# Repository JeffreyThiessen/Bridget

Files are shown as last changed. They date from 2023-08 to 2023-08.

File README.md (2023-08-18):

# Bridget Custom
This repo has my custom stl files for Flatbox rev4 PCB's, modified from SGF Devices repo.

finished

files https://github.com/JeffreyThiessen/Bridget/tree/main/v2_custom

read [v2_custom/v2_custom.md](https://github.com/JeffreyThiessen/Bridget/blob/main/v2_custom/v2_custom.md) for details

# Bridget
3D Printable Files for SGF Bridget controller. The case is a modified version of the Flatbox rev4 by jfedor (https://github.com/jfedor2/flatbox). The buttons are a modified version of the Egg On Rice buttons by b1nc (https://github.com/b1nc/Egg-On-Rice-Controller). It is designed to fit a Flatbox rev4 PCB without modification.  
  
v1 of this case is no longer used. v2 was developed to increase rigidity, ease assembly, and allow for future additions. When assembling v2, tolerances are tight and may require a SMALL amount of pressure to seat the sides into other pieces. If the pieces do not snap together with small amounts of force, your printer/filament may need tuning to print the dimensions more accurately, or you may need to do some sanding. You can also always go back to printing v1.  
  
Each case requires the following for full assembly:  
1x top case  
1x bottom case  
2x sides - IMPORTANT NOTE - the portion of the side panel that seats into the top case is deeper than the portion that seats into the bottom case. If your case doesn't close without a gap, you probably have the side panel upside down.  
11x small button  
1x big button  
7x M2x3 or M2x4 heat set brass inserts (https://amazon.com/gp/product/B0B8GN63S2)  
7x M2x5 or M2x6 countersunk flat screws (https://amazon.com/gp/product/B0B54FHHDW)  
4x 6mm/0.25in bumpons (https://amazon.com/dp/B016GWHSBE)  
  
All parts can be printed without supports. You may or may not need a brim for the larger case pieces depending on how good your filament's bed adhesion is. Use the ideal layer height for your printer. For our production runs, these are printed with default Optimal settings for our printers in Bambu Lab. Use of a fast CoreXY printer like a Voron or Bambu is advised if you'd like to make them regularly, as they can take quite a while to print.

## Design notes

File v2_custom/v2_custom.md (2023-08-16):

These files work with files in v2/ and Buttons/

There are 2 versions of the custom buttons, with and without bevel. btn4 is for the top row 4th button and btn8 is for the bottom row 4th button.

top_hole_btn_fragment.stl is included for if you want to modify the regular v2 case with the round top button design without the custom button shapes.

For multicolour prints with cutouts, add pauses in your slicer settings after layer 3 and layer 7 to switch filaments back and forth. Have at least 4 layers of colour 2 for better results.

example: 

For best looking results with cutouts, set your supports to be as far from your build as possible while still being able to bridge the material. This way you will have less of the outerlayer colour melting into the 2nd colour.



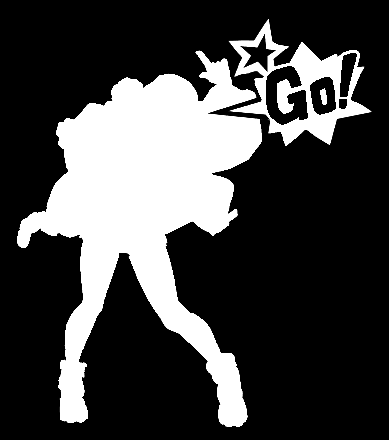
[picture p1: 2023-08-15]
v2_custom/bridget super cutout.png

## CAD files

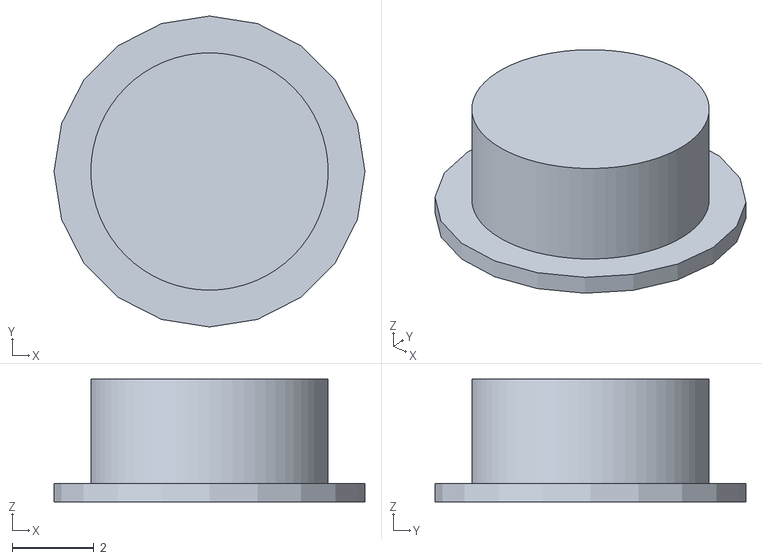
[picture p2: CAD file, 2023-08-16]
v2_custom/btn_tiny.stl
7.60 x 7.60 x 3.00

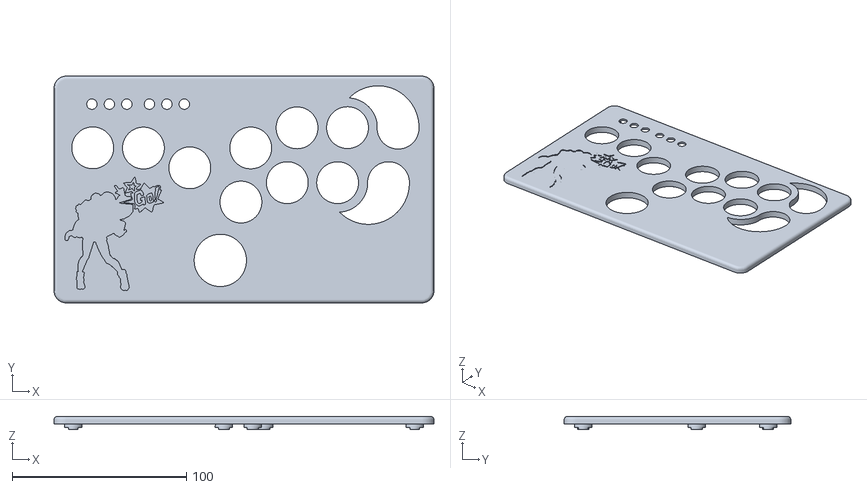
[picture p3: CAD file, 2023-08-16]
v2_custom/top_custom_with_cutout.stl
218.0 x 130.1 x 7.70

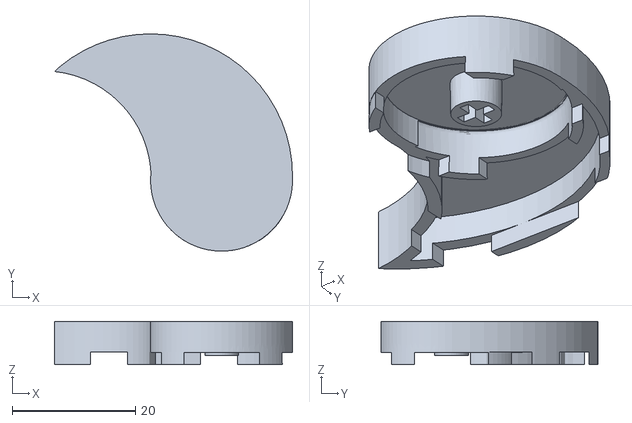
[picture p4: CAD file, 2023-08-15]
v2_custom/btn4.stl
38.6 x 35.2 x 7.00

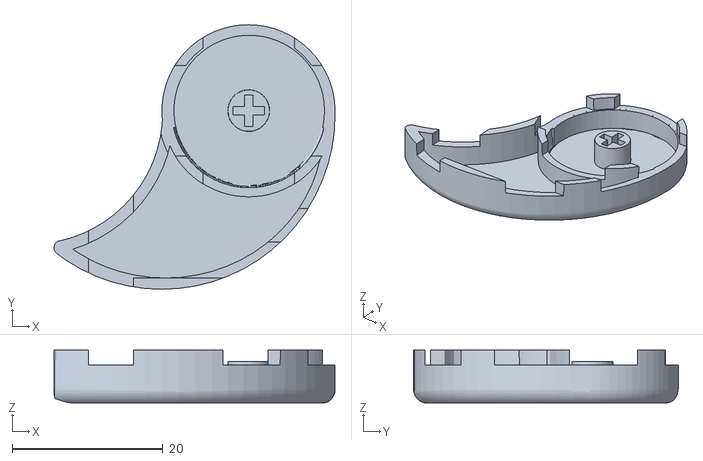
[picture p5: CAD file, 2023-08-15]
v2_custom/btn8bevel.stl
37.3 x 35.2 x 7.00

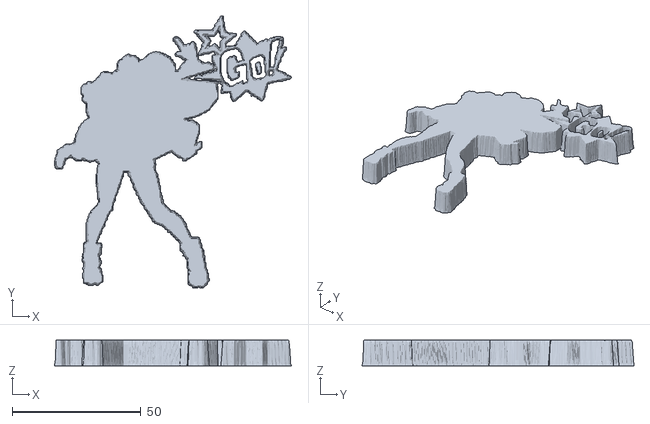
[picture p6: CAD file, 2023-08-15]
v2_custom/ImageToStl.com_bridget super cutout.stl
92.1 x 105.6 x 10.0

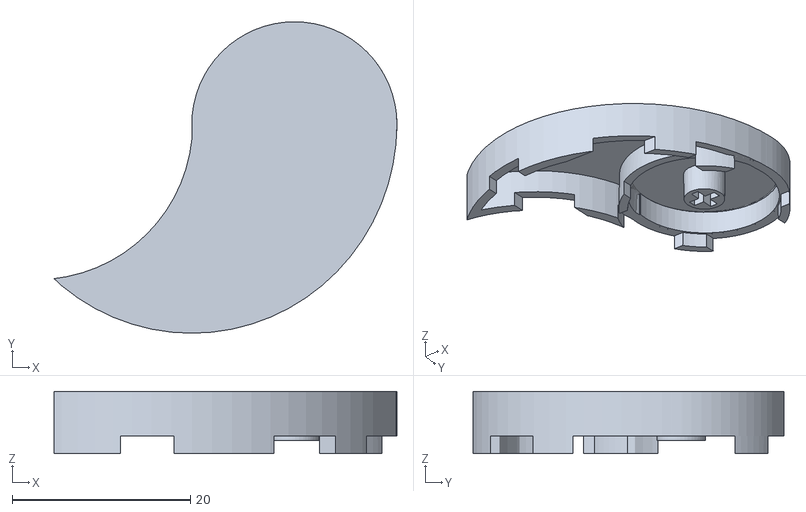
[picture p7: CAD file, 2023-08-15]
v2_custom/btn8.stl
38.4 x 34.9 x 7.00

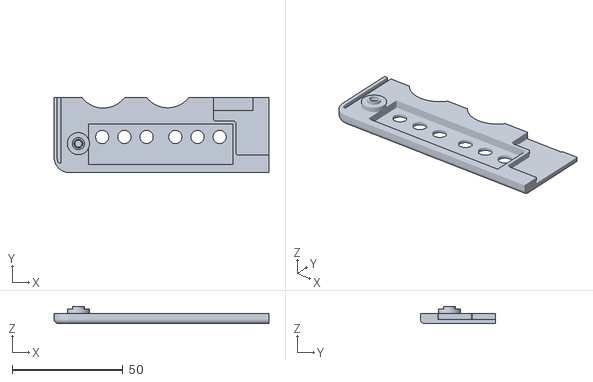
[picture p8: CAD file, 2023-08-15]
v2_custom/top_hole_btn_fragment.stl
97.0 x 34.0 x 7.70

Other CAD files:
v2_custom/btn4bevel.stl
v2_custom/top_custom.stl
